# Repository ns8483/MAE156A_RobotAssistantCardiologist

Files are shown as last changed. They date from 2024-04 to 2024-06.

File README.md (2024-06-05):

# MAE156A_RobotAssistantCardiologist
<h2> Contributions:

<h6> Anika Bhattacharya: Knob Engagement and Housing Design and Fabrication<br>
Cristian Nunez-Alcazar: Manuafacturing Lead, Multiplane Angle Mechanism Design and Fabrication<br>
Noah Jones: Custom Stepper and Linear Actuator Libraries, Data Analysis, Tip Control Mechanism Design and Fabrication, Arm Design<br>
Nithya Srinivasan: Software Lead, Knob Engagement Design, Arm Fabrication, Controller Logic and Integration

<h2>Project Background:

<h6>Transesophageal Echocardiography (TEE): ultrasound imaging technique for the heart. It is used to analyze heart defects and guides repair of valves. This procedure is conducted from inside the food pipe (esophagus) via a catheter.
<br><br>

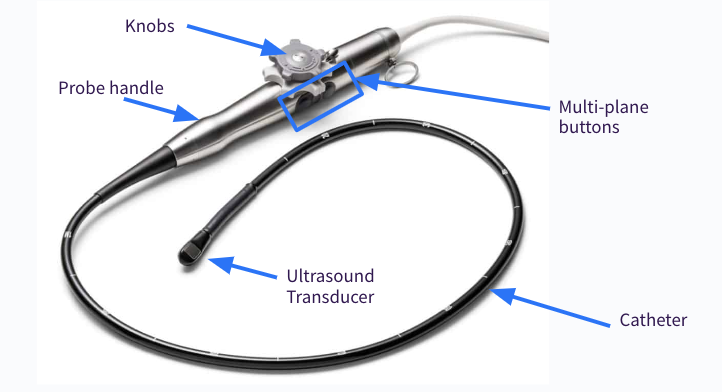
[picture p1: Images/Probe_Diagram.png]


<h2>Problem Definition Overview:

<h6>The current manual procedure is time Consuming (2 hours long), ergonomically challenging, has limited precision, and extensive exposure to harmful x-ray radiation from fluoroscopy.
<br><h4>**Our goal: Remotely operate procedure after initial manual catheter insertion.**</b>

<h6>Diagram of Existing Manual Procedure: <br><br>

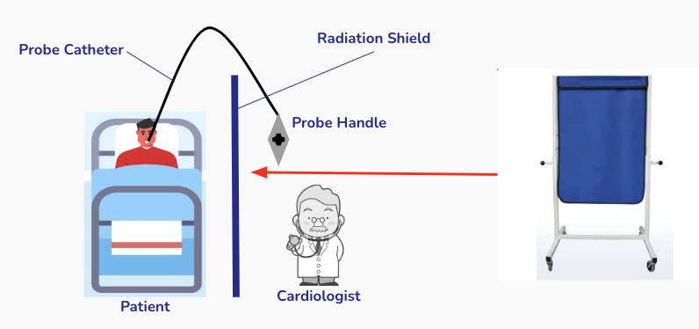
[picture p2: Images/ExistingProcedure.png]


Diagram of Procedure Setup with our Mechanism

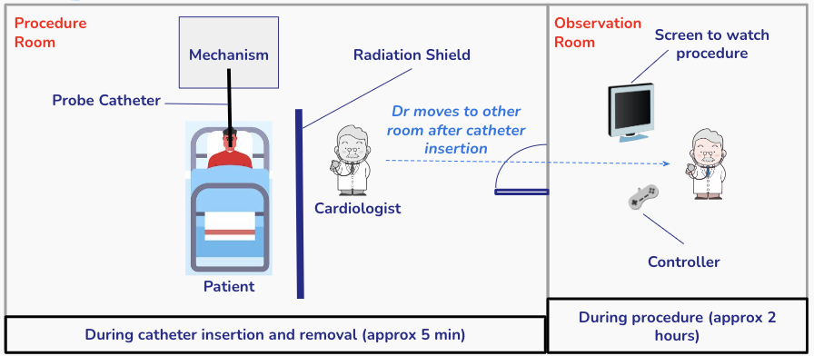
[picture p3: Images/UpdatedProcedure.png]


<h2>Project Video: <br><br>

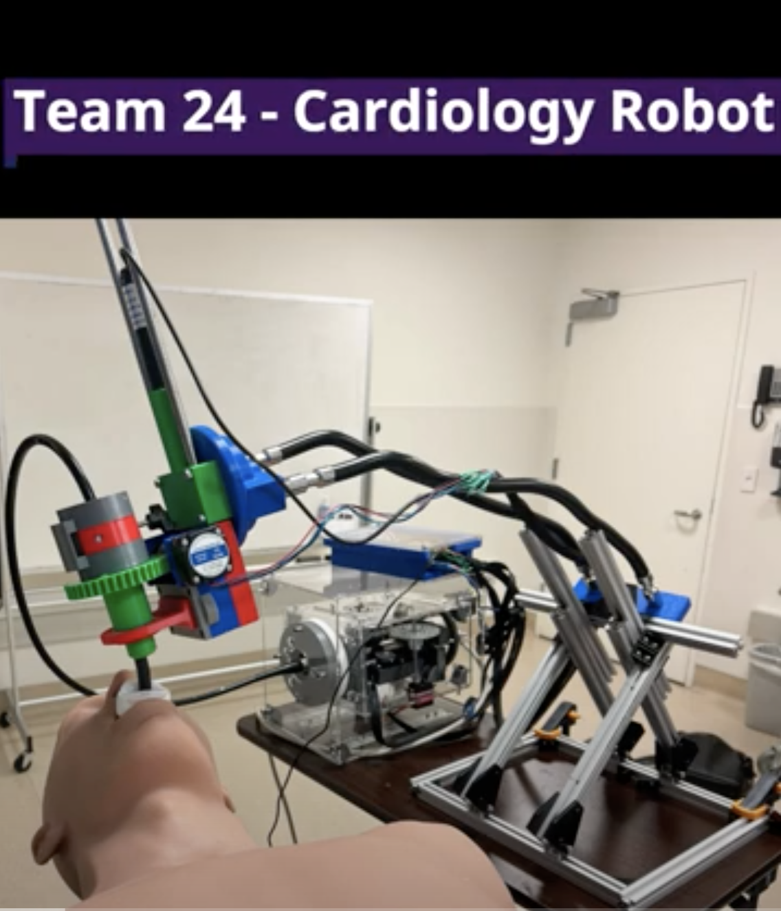
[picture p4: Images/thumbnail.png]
IMAGE ALT TEXT HERE (https://youtu.be/6WJvAoj5yTA?feature=shared)


<h2> Schematic of Overall Design: <br><br>

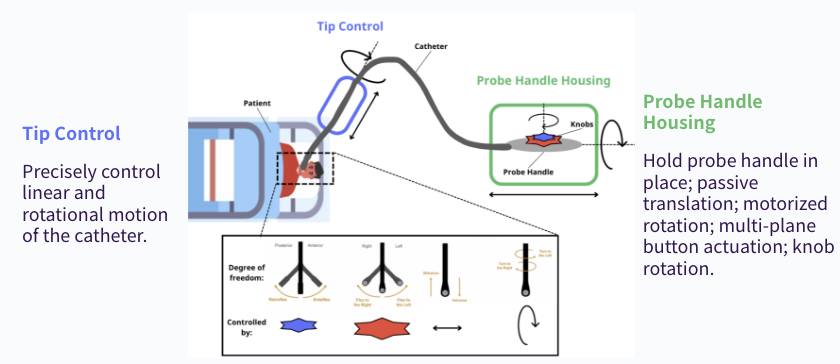
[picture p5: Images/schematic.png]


<h2> CAD Rendering of Design: <br><br>

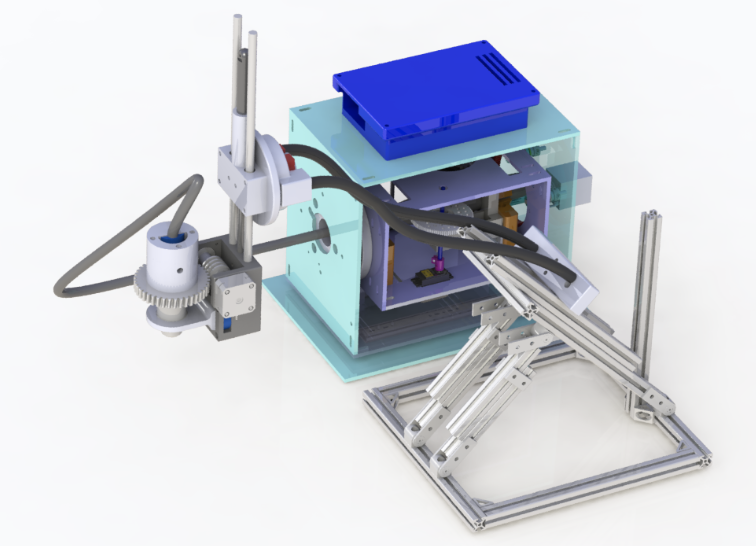
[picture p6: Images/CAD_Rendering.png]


<h2> Final Fabrication: <br><br>

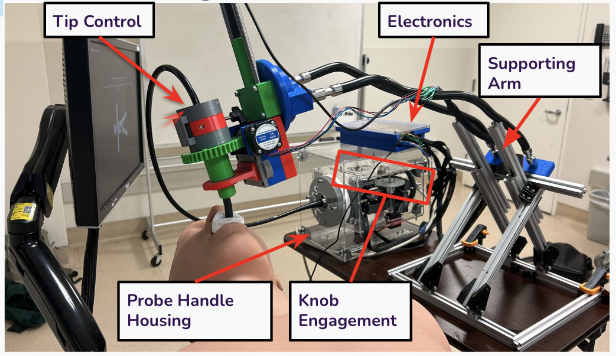
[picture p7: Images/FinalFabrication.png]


<h2> Controller:

<h6> This allows for full control of rotatiton of tip and housing, linear translation, knob engagement, step size adjustment, multi-plane angle control, and position memory as shown in the video.<br>

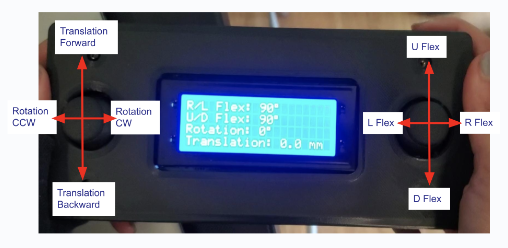
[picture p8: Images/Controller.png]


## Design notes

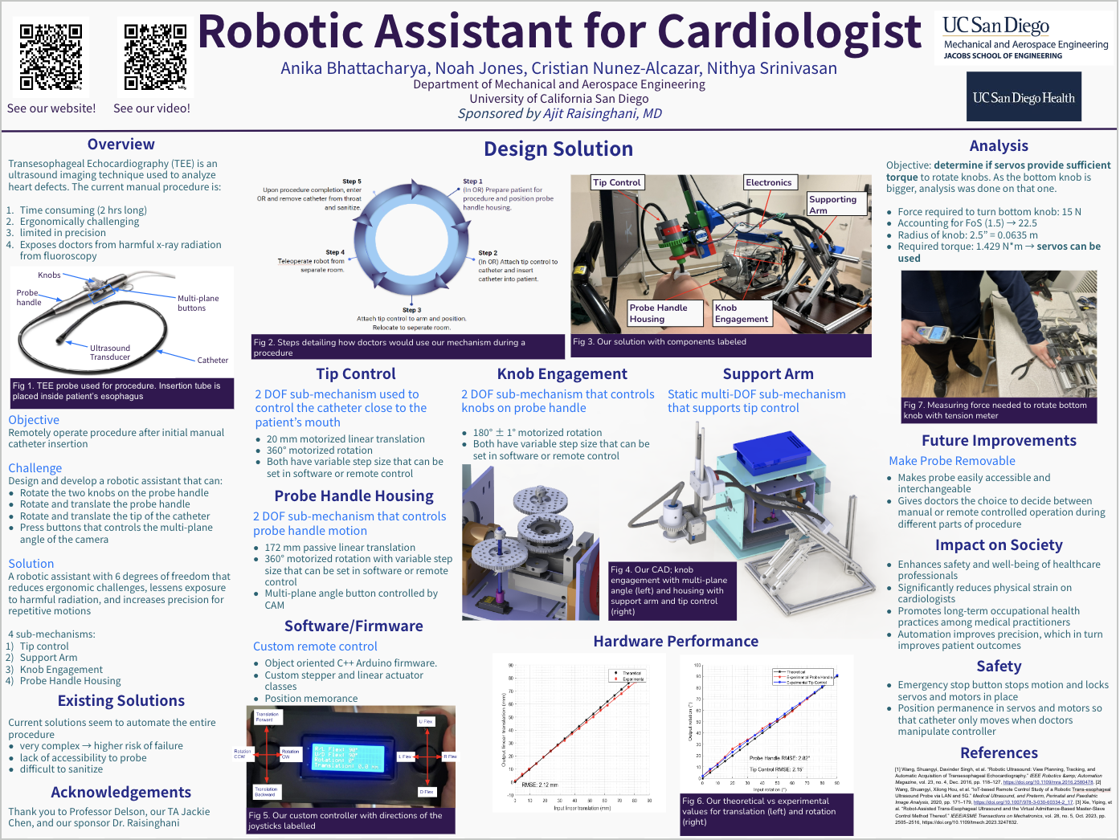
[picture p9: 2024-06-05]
Images/Poster.png

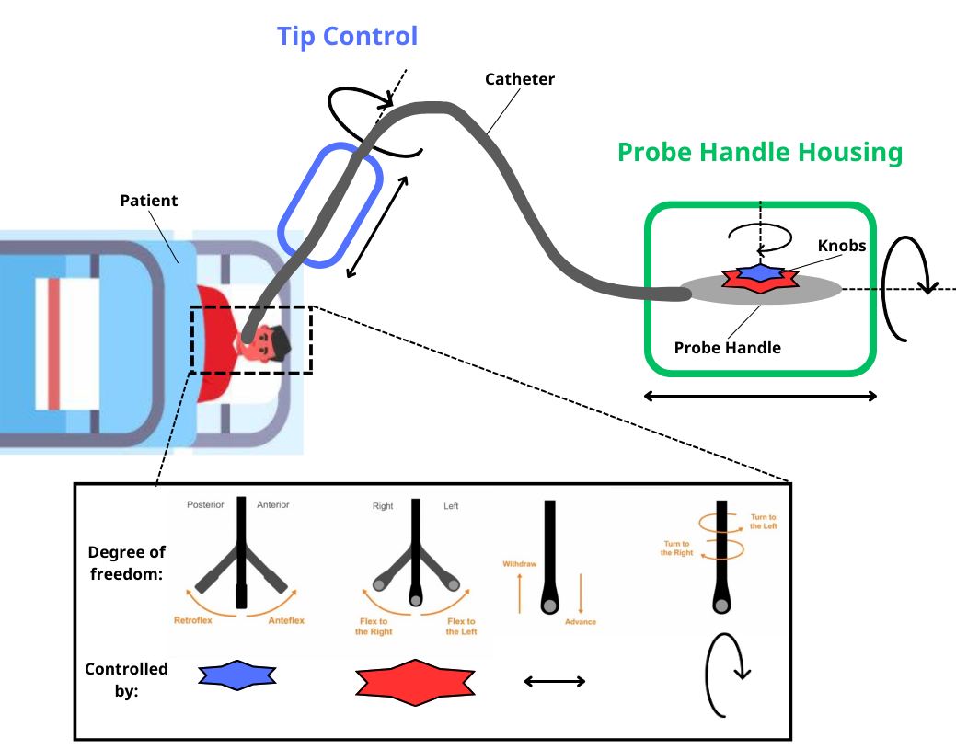
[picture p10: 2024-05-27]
Images/System Diagram Cropped.png

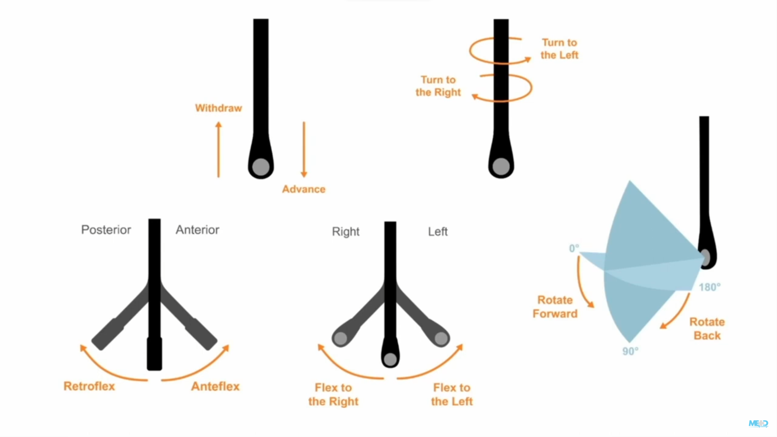
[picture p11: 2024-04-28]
Images/DOfs.png

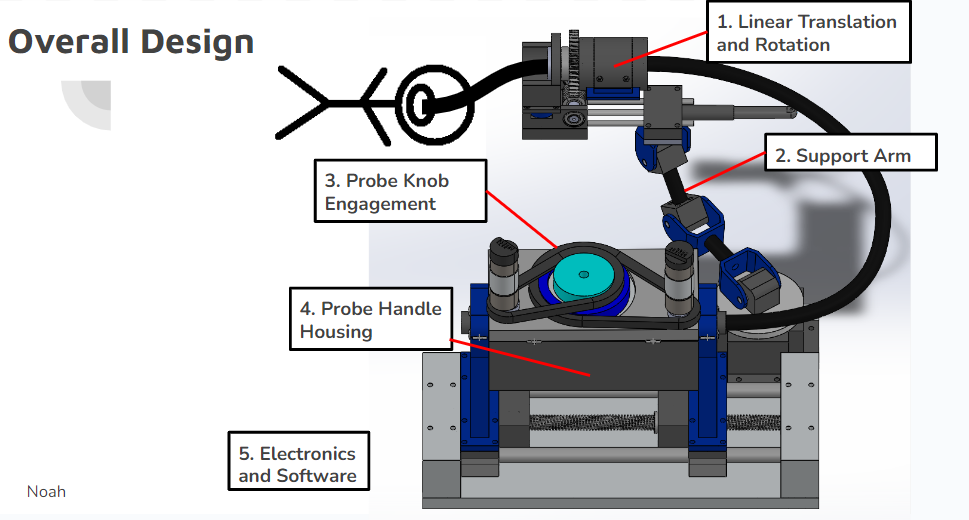
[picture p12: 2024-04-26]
Images/system_diagram.png

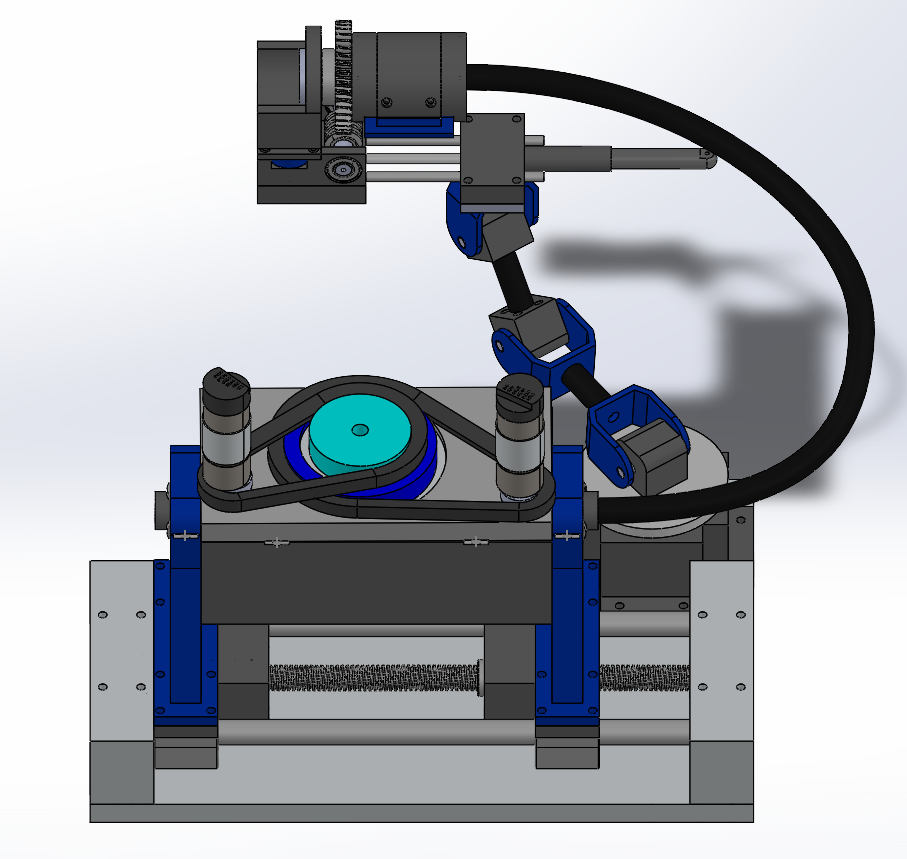
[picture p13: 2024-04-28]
Images/system_model.png

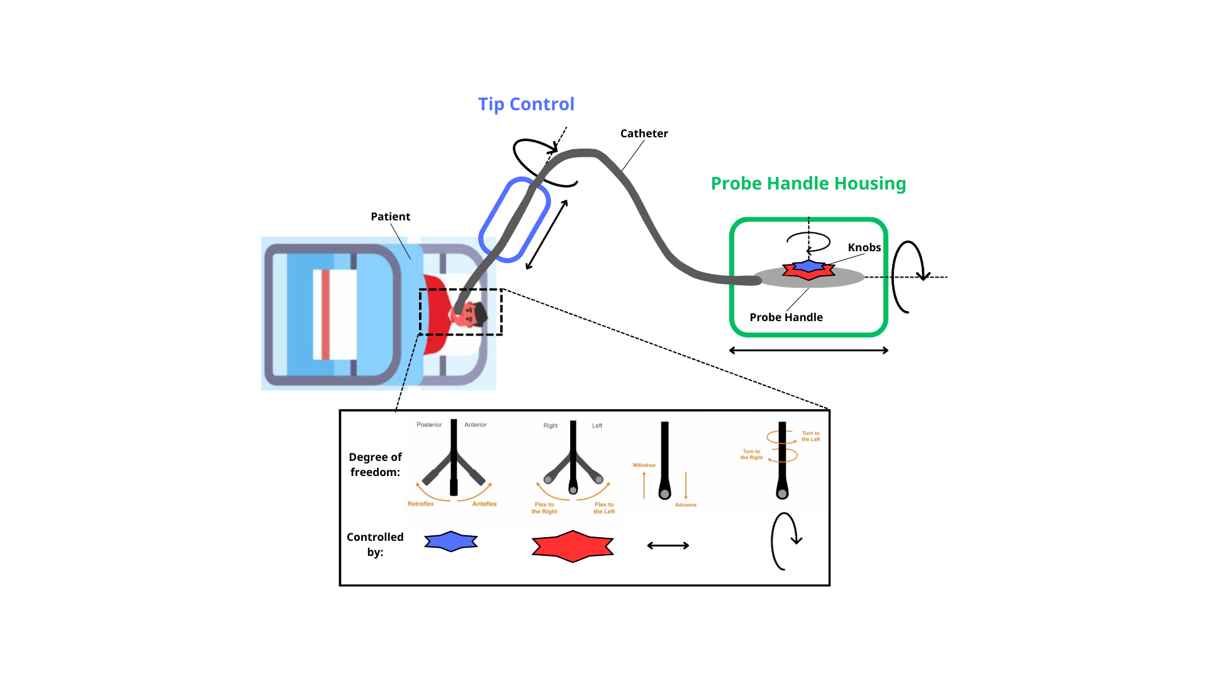
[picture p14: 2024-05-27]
Images/System Diagram.png

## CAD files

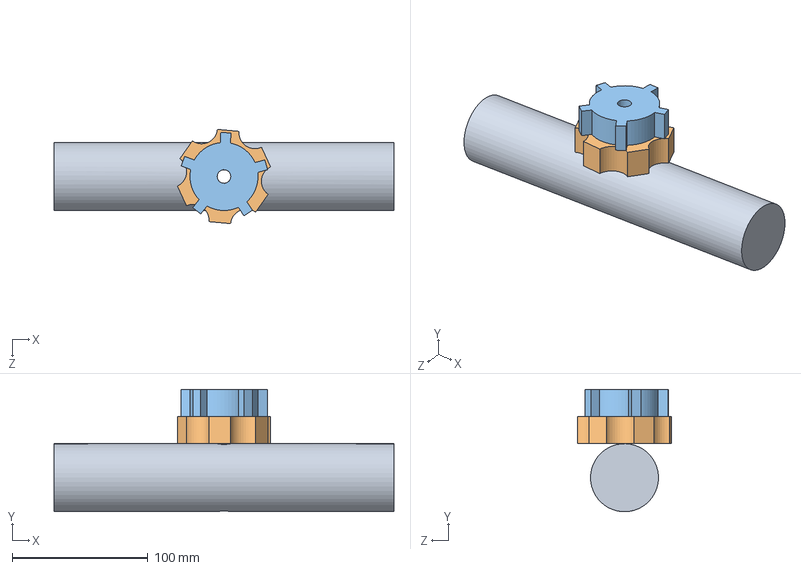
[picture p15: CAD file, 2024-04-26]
CAD/Probe and Housing/probe_mechanism.SLDASM
250.0 x 90.0 x 69.3 mm
probe
big_knob
small_knob

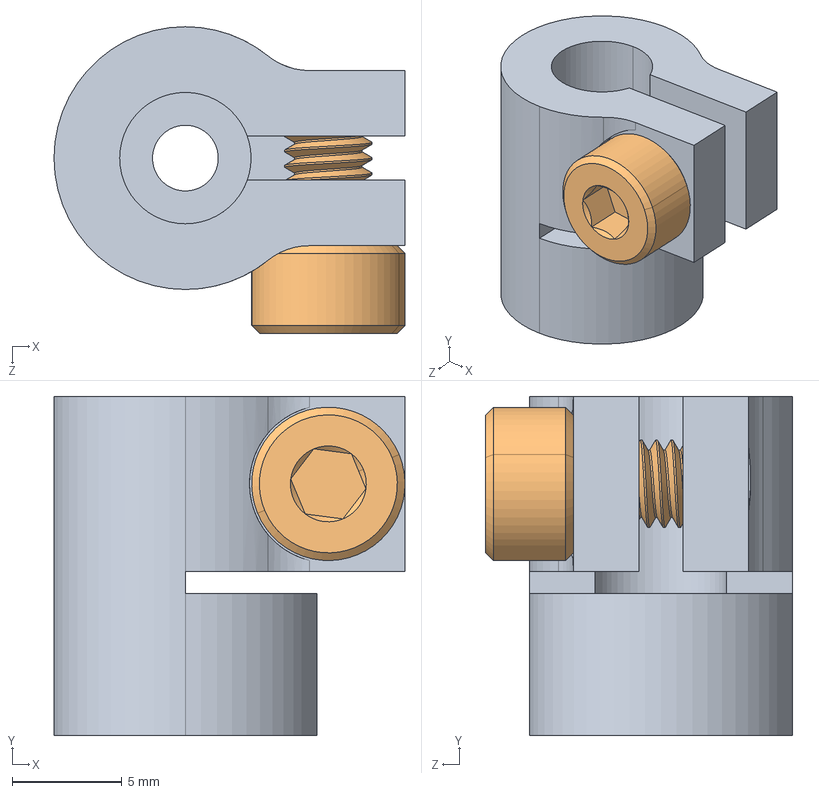
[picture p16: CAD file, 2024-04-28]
CAD/knob engagement, motorized rotation, passive translation/4001-0025-0006 assembly.STEP
16.0 x 15.5 x 14.0 mm
2800-0004-0008_90128A207

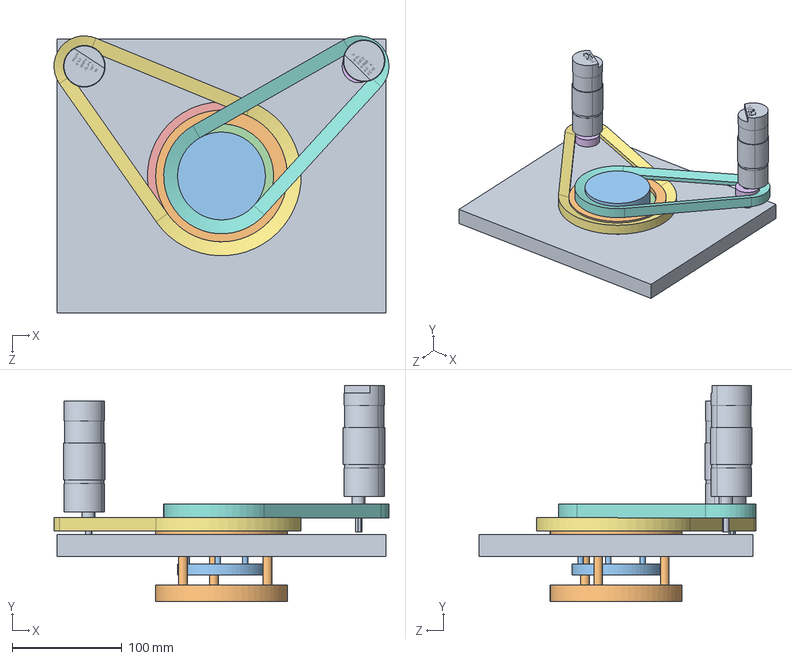
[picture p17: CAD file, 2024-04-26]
CAD/Probe and Housing/top.SLDASM
305.3 x 196.9 x 252.7 mm
lid
big_knob_cap
small_knob_cap
NeedleBearing_PartNumberNTB7095
NeedleBearing_PartNumberNTB100135
dummy pulley x 2
Belt1-8^top
Belt2-9^top
am-2964a Neverest Classic 40 x 2

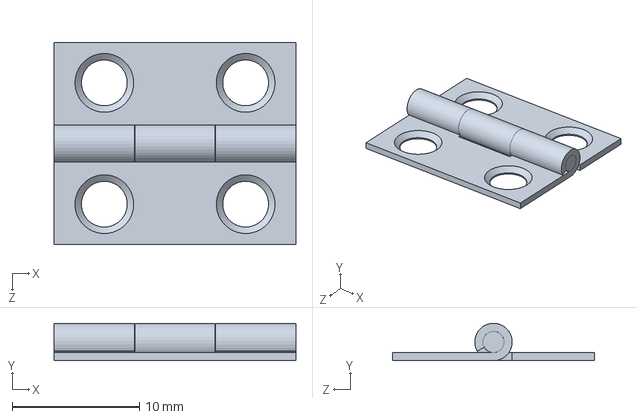
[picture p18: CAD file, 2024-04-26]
CAD/Base/1603A2_Surface-Mount Hinge with Holes.SLDPRT
19.1 x 2.95 x 15.9 mm

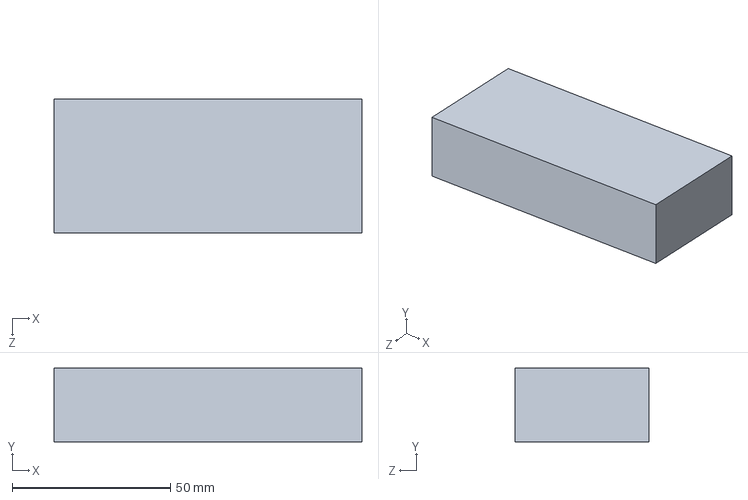
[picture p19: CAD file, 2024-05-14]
CAD/Electronics/Display.SLDPRT
97.3 x 23.2 x 42.4 mm

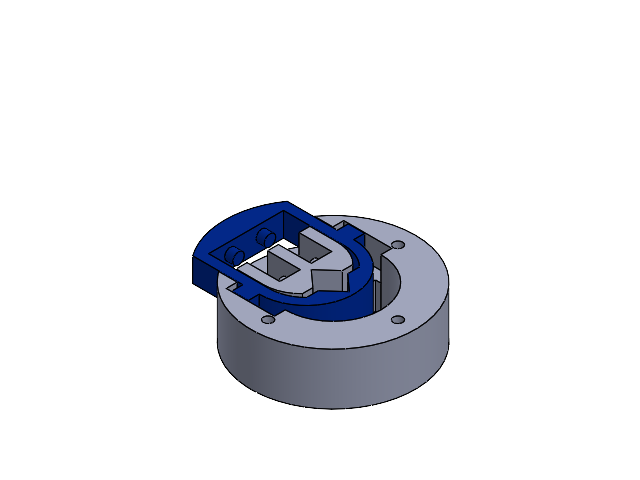
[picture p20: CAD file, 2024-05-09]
CAD/Attachement/Lock Mechanism.SLDASM
Lock Base x 2
Lock Pin
Lock Lid
Lock Internal Block

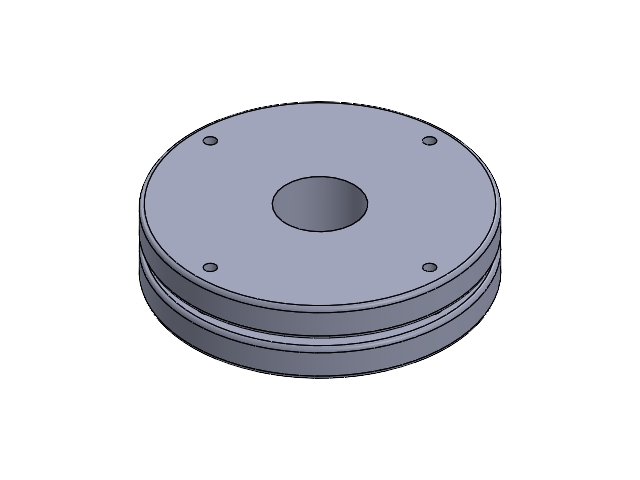
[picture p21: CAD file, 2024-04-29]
CAD/knob engagement, motorized rotation, passive translation/Bearing Mount Assembly.SLDASM
Inner Bearing Mount
5972K295_Ball Bearing 40mm ID
Outer Bearing Mount

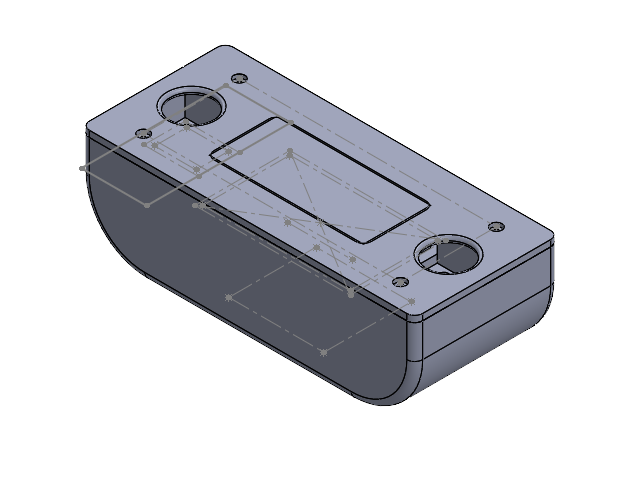
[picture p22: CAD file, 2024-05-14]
CAD/Electronics/Controller Assembly.SLDASM
Controller Back
Controller Front
Display
Controller Lid

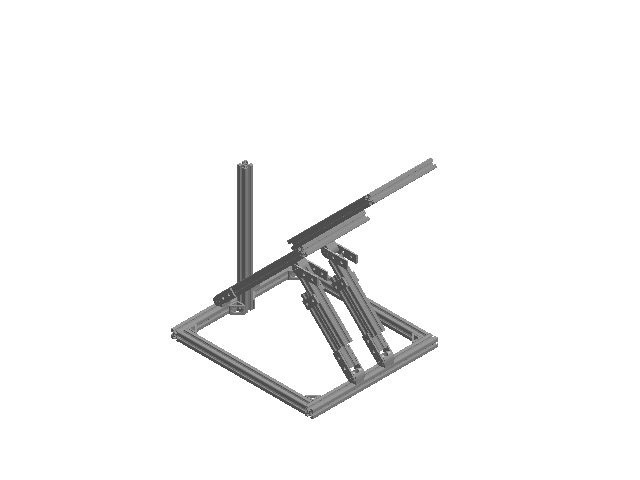
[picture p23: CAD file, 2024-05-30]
CAD/Arm V2/Arm V2.SLDASM
5537T044_T-Slotted Framing x 9
5537T219_T-Slotted Framing x 6
T-Slotted Framing (150mm L) x 6
5537T498_T-Slotted Framing x 8
5537T944_T-Slotted Framing x 4

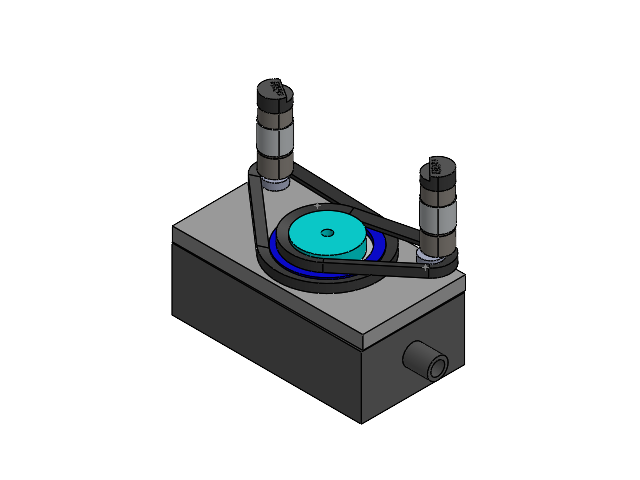
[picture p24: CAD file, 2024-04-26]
CAD/Probe and Housing/Probe and Housing Assembly.SLDASM
New Probe Box
New Probe
lid
big_knob_cap
small_knob_cap
NeedleBearing_PartNumberNTB7095
NeedleBearing_PartNumberNTB100135
dummy pulley x 2
Belt1-8^top
Belt2-9^top
am-2964a Neverest Classic 40 x 2
Dial Large
Dial Small
Hinge 2 x 2
Hinge 1 x 2

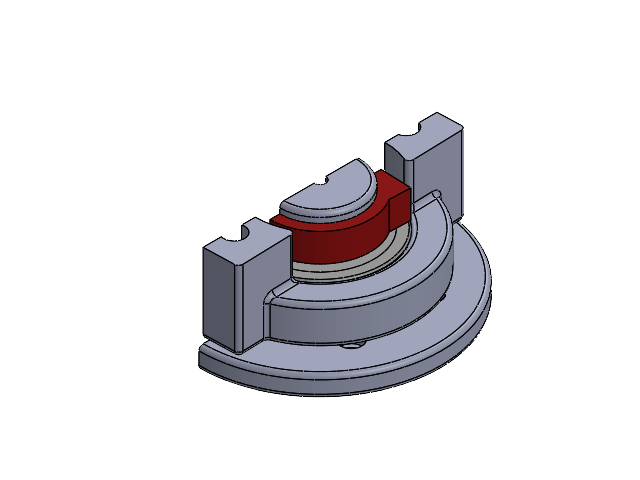
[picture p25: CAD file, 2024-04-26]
CAD/Attachement/Rotator Assembly.SLDASM
Rotator Pin
5972K608_Ball Bearing 30mm ID
Rotator Holder
Rotator Cap
Clamp

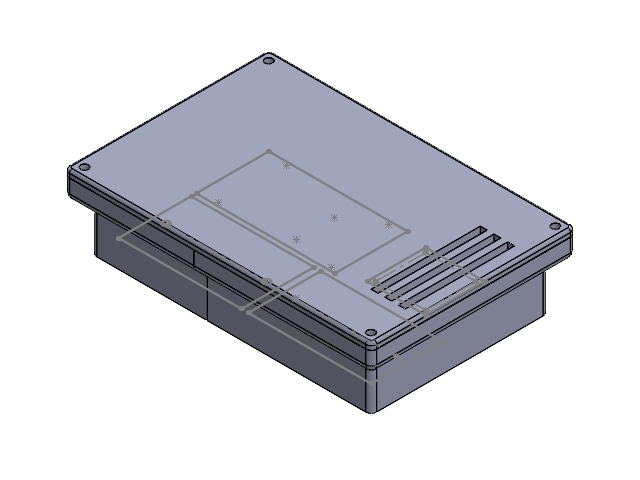
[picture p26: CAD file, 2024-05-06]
CAD/Electronics/Cable Box Assembly.SLDASM
Cable Box (male)
Cable Box (female)
Cable Box Lid

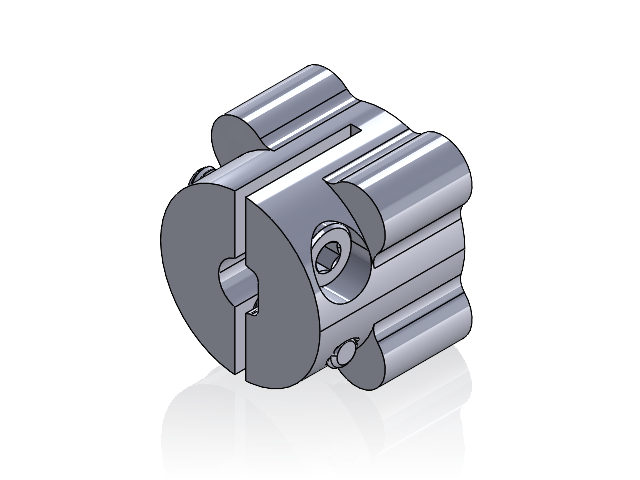
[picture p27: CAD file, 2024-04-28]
CAD/knob engagement, motorized rotation, passive translation/1310-0016-1006 Assembly.SLDASM
1310-0016-1006.STEP
2800-0004-0014_90128A207.STEP x 2

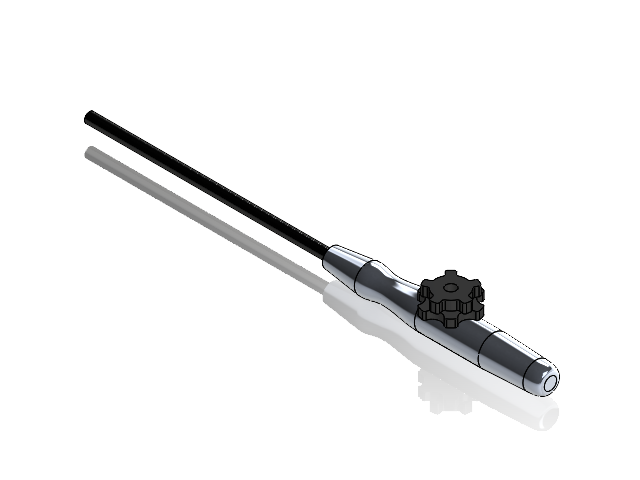
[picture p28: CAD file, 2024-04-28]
CAD/knob engagement, motorized rotation, passive translation/FullProbe.SLDASM
New Probe
Dial Large
Dial Small

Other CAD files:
CAD/Attachement/Micro Linear Actuator 100mm.SLDASM
CAD/Attachement/Square Lock Assembly.SLDASM
CAD/knob engagement, motorized rotation, passive translation/4002-0005-0006 assembly.SLDASM
CAD/Entire Assembly/PJ1045WH Nylon Handle.SLDPRT
CAD/Arm V2/5537T044_T-Slotted Framing.SLDPRT
CAD/Arm V2/5537T219_T-Slotted Framing.SLDPRT
CAD/Arm V2/5537T231_T-Slotted Framing.SLDPRT
CAD/Arm V2/5537T498_T-Slotted Framing.SLDPRT
CAD/Arm V2/5537T944_T-Slotted Framing.SLDPRT
CAD/Arm V2/T-Slotted Framing (150mm L).SLDPRT
CAD/Arm/1.25 D Pipe Mount.SLDPRT
CAD/Arm/3136N723_T-Slotted Framing.SLDPRT
CAD/Arm/5537T915_T-Slotted Framing.SLDPRT
CAD/Arm/Arm Assembly.SLDASM
CAD/Arm/Arm Base Mount.SLDPRT
CAD/Arm/Arm Base Plate.SLDPRT
CAD/Arm/Arm Bracket.SLDPRT
CAD/Arm/Arm Disk.SLDPRT
CAD/Arm/Arm Motor.SLDPRT
CAD/Arm/Arm Mount.SLDPRT
CAD/Arm/Arm Tube Holder.SLDPRT
CAD/Arm/Joint.SLDASM
CAD/Arm/M6x12FHCS_91294A236.SLDPRT
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

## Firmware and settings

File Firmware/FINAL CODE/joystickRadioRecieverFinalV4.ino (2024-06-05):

// Libraries
#include <Servo.h>
#include <SPI.h>
#include <nRF24L01.h>
#include <RF24.h>
#include "LinearActuator.h"
#include "Stepper.h"
// Tip Rotation
int EN_TIP_PIN = 10; // Enable
int STEP_TIP_PIN = 9; // Step
int DIR_TIP_PIN = 13; // Direction
int tipGearRatio = 40; //40:1 ratio
// Handle Rotation
int EN_HANDLE_PIN = 4; // Enable
int STEP_HANDLE_PIN = 6; // Step
int DIR_HANDLE_PIN = 5; // Direction
double handleGearRatio = 6.67; //6.67:1 ratio
// Linear Actuator
int ENA_PIN_NUM = 24; // Motor contoller voltage control (PWM) (change)
int IN1_PIN_NUM = 26; // Motor direction (change)
int IN2_PIN_NUM = 28; // Motor direction (change)
int ENCODERA_PIN_NUM = 3; // Hall Sensor digital signal 
int ENCODERB_PIN_NUM = 2; // 90 deg phase difference
// Knob Rotation
int SERVO_TOP_PIN = 12; // servo for top knob (change)
int SERVO_BOT_PIN = 11; // servo for bottom knob (change)
int servoTopPos = 90; // default position
int prevServoTopPos = servoTopPos; // keeps track of previous servo position
int servoBotPos = 90; // default position
int prevServoBotPos = servoBotPos; // keeps track of previous servo position
// Multiplane Angle Control
int MULTIPLANE_PIN = 44;
int critAnglePos = 30; //CHANGE THESE VALUES OR IT WON'T WORK MIGHT BREAK**************************************
int critAngleNeg = 90;
int neutralAngle = 60;
int multiPlaneMark = 0; //0 means that currently is at neutral, 1 means that currently at CCW mark, -1 means that at CW mark
// NRF Transceiver
int NRF_CSN_PIN = 8;
int NRF_CE_PIN = 7;
int NRF_SCK_PIN = 52;
int NRF_MOSI_PIN = 51;
int NRF_MISO_PIN = 50;
const byte addresses[][6] = {"00001", "00002"};
// Global Vars
float linearStepSize = 1.00; // default linear step size [mm]
float rotationStepSize = 1.00; // default rotation step size [deg]
float servoStepSize = 1.00; // default knob rotation step size [deg]
int microSteps = 8; // default number of stepper microsteps
float joyCritical = 80.0; // Joystick critical actuation value after mapping
float joyPosArray[6] = {}; // [0]: x-right joystick [1]: y-right joystick [2]: x-left joystick [3]: y-left joystick
float posMetrics[4] = {}; // [0]: top servo, [1]: bottom servo, [2]: stepper motor, [3]: linear actuator
//Global objects
Servo servoTop; // top servo object creation
Servo servoBot; // bottom servo object creation
Servo multiplaneServo; //multiplane angle control servo
RF24 radio(NRF_CE_PIN,NRF_CSN_PIN); // radio object creation

//keeps track of what was changed so that can keep track for backtracking.
float prevPos[4] = {90,90,0,0};
float savedPos[4] = {90,90,0,0};

void setup() {
  Serial.begin(115200);
  Serial.println("Calibrating...\n");
  // servo setup
  for(int i=0;i<=servoTopPos;i++){
    servoTop.write(servoTopPos); // send servos to home right away so that will do when attached faster
    servoBot.write(servoBotPos);
    delay(20);
  }
  multiplaneServo.write(neutralAngle);
  servoTop.attach(SERVO_TOP_PIN); // attach feedback pins to servo objects
  servoBot.attach(SERVO_BOT_PIN);
  multiplaneServo.attach(MULTIPLANE_PIN);
  // radio setup
  radio.begin();
  radio.openReadingPipe(1, addresses[1]); // 00002
  radio.openWritingPipe(addresses[0]);
  radio.setPALevel(RF24_PA_MAX);
}

void loop(){
  // initialize class objects
  Stepper stepperTip(EN_TIP_PIN, STEP_TIP_PIN, DIR_TIP_PIN, microSteps, tipGearRatio);
  Stepper stepperHandle (EN_HANDLE_PIN, STEP_HANDLE_PIN, DIR_HANDLE_PIN, microSteps, handleGearRatio);
  Stepper stepperArray[] = {stepperTip, stepperHandle};
  LinearActuator linearActuator(ENA_PIN_NUM, IN1_PIN_NUM, IN2_PIN_NUM, ENCODERA_PIN_NUM, ENCODERB_PIN_NUM);
  Serial.println("Calibrating Complete!");
  while(true) {
    radio.startListening();
    delay(5);
    if (radio.available()) {
      //Serial.println("connected");2
      radio.read(&joyPosArray, sizeof(joyPosArray));
      delay(5);
      //move top servo CW
      if (joyPosArray[0] <= -1*joyCritical){
        if (servoTopPos != 0){
          servoTopPos = servoTopPos - servoStepSize;
          servoTop.write(servoTopPos);
          delay(200); //wait for servo to reach this position
          radio.flush_rx();
          prevPos[0] = servoTopPos;
        }
        //move top servo CCW
      }else if (joyPosArray[0] >= joyCritical){
        if (servoTopPos != 180){
          servoTopPos = servoTopPos + servoStepSize;
          servoTop.write(servoTopPos);
          delay(200); //wait for servo to reach this position
          radio.flush_rx();
          prevPos[0] = servoTopPos;
        }
        //move bottom servo CW
      }else if (joyPosArray[1] <= -1*joyCritical){
        if (servoBotPos != 0){
          servoBotPos = servoBotPos - servoStepSize;
          servoBot.write(servoBotPos);
          delay(200); //wait for servo to reach this position
          radio.flush_rx();
          prevPos[1] = servoBotPos;
        }
        //move botttom servo CCW
      }else if (joyPosArray[1] >= joyCritical){
        if (servoBotPos != 180){
          servoBotPos = servoBotPos + servoStepSize;
          servoBot.write(servoBotPos);
          delay(200); //wait for servo to reach this position
          radio.flush_rx();
          prevPos[1] = servoBotPos;
        }
        //stepper CCW rotation
      }else if (joyPosArray[2] >= joyCritical){ // if left joystick points right and stepper is not already moving
        Stepper::incrementalPosMulti(rotationStepSize,0,stepperArray); // synchronous stepper movement direction 1 (CW)
        radio.flush_rx();
        prevPos[2] = stepperArray[0].currentAngle;
        //stepper CW rotation
      }else if (joyPosArray[2] <= -1*joyCritical){ // if left joystick points left and stepper is not already moving
        Stepper::incrementalPosMulti(rotationStepSize,1,stepperArray); // synchronous stepper movement direction 0 (CCW)
        radio.flush_rx();
        prevPos[2] = stepperArray[0].currentAngle;
        //linear actuator extension
      }else if (joyPosArray[3] >= joyCritical){ // if left joystick points up
        linearActuator.incrementalPos(linearStepSize, 1); // linear actuator extension
        radio.flush_rx();
        prevPos[3] = linearActuator.position;
        //linear actuator retraction
      }else if (joyPosArray[3] <= -1*joyCritical){ // if left joystick points down
        linearActuator.incrementalPos(linearStepSize, 0); // linear actuator retraction
        radio.flush_rx();
        prevPos[3] = linearActuator.position;
      }
      //look in transmitter code for explanation of this element
        //1 and 2 denote new step size change of servos, 3 is for stepper, 4 is for linear actuator
      else if (joyPosArray[4] == 1){
        servoStepSize = servoStepSize + 1;
      } else if (joyPosArray[4] == -1) {
        servoStepSize = servoStepSize - 1;
      } else if (joyPosArray[4] == 2) {
        rotationStepSize = rotationStepSize + 1;
      } else if (joyPosArray[4] == -2) {
        rotationStepSize = rotationStepSize - 1;
      } else if (joyPosArray[4] == 3) {
        linearStepSize = 5*linearStepSize;
      } else if (joyPosArray[4] == -3) {
        linearStepSize = 0.5*linearStepSize;
      } //controls multiplane buttons
          //servo rotates between pressing each button and neutral positions
      else if (joyPosArray[5] == 1) {
        if (multiPlaneMark < 1) {
          if (multiPlaneMark ==0) {
            multiplaneServo.write(critAnglePos);
            multiPlaneMark = 1;
          } else if ( multiPlaneMark== -1) {
            multiplaneServo.write(neutralAngle);
            multiPlaneMark = 0;
          }
          delay(200);
          radio.flush_rx();
        }
        Serial.println(multiPlaneMark);
        Serial.println(multiplaneServo.read());
      } else if(joyPosArray[5] == -1) {
        if (multiPlaneMark > -1) {
          if (multiPlaneMark ==0) {
            multiplaneServo.write(critAngleNeg);
            multiPlaneMark = -1;
          } else if (multiPlaneMark == 1) {
            multiplaneServo.write(neutralAngle);
            multiPlaneMark = 0;
          }
          delay(200);
          radio.flush_rx();
        }
        Serial.println(multiPlaneMark);
        Serial.println(multiplaneServo.read());
      }
      //look in transmitter code for explanation of this element
        //can save and restore positions
      else if (joyPosArray[5] == 2) {
        //saving position
        Serial.println("**************************");
        Serial.println(prevPos[0]);
        Serial.println(prevPos[1]);
        Serial.println(prevPos[2]);
        Serial.println(prevPos[3]);
        Serial.println("**************************");
        for (int i = 0; i < 4; i++) {
          savedPos[i] = prevPos[i];
        }
      } else if (joyPosArray[5] == 3) {
        //restoring position
        Serial.println("**************************");
        Serial.println(savedPos[0]);
        Serial.println(savedPos[1]);
        Serial.println(savedPos[2]);
        Serial.println(savedPos[3]);
        Serial.println("**************************");
        servoTop.write(savedPos[0]);
        servoTopPos = savedPos[0];
        radio.flush_rx();
        servoBot.write(savedPos[1]);
        servoBotPos = savedPos[1];
        radio.flush_rx();
        float stepperDiff = stepperArray[0].currentAngle - savedPos[2];
        if (stepperDiff < 0) {
          Stepper::incrementalPosMulti(abs(stepperDiff),1,stepperArray); // synchronous stepper movement direction 0 (CCW)
          radio.flush_rx();
        } else {
          Stepper::incrementalPosMulti(abs(stepperDiff),0,stepperArray); // synchronous stepper movement direction 0 (CCW)
          radio.flush_rx();
        }
        float linDiff = linearActuator.position - savedPos[3];
        if (linDiff < 0) {
          linearActuator.incrementalPos(abs(linDiff), 1);
          radio.flush_rx();
        } else {
          linearActuator.incrementalPos(abs(linDiff), 0);
          radio.flush_rx();
        }
      }
    }
    radio.flush_rx();
    radio.stopListening();
    delay(5);
    //writing to controller to update LCD display
    posMetrics[0] = servoTopPos;
    posMetrics[1] = servoBotPos;
    posMetrics[2] = stepperArray[0].currentAngle;
    posMetrics[3] = linearActuator.position;
    radio.write(&posMetrics, sizeof(posMetrics));
  }
}

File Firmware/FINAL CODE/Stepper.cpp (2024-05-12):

/*
  Stepper.cpp - Library for controlling Stepper Motors.
  Provides simultaneously, non-blocking stepper motor control,
  that adjusts for gear ratio discrepancies to maintain synchronized speeds.

  Created by Noah L. Jones, May 10, 2024.
  Released into the public domain.
*/

#include "Stepper.h"
#include "Arduino.h"

// Setup Constructor 
Stepper::Stepper(int EN_PIN_NUM, int STEP_PIN_NUM, int DIR_PIN_NUM, int microStepNum, double gearRatioNum) {
  enPin = EN_PIN_NUM;
  stepPin = STEP_PIN_NUM;
  dirPin = DIR_PIN_NUM;
  microSteps = microStepNum;
  gearRatio = gearRatioNum;
  stepsPerRevolution = 200*microSteps;  // Change this according to your motor's specification
  pinMode(enPin, OUTPUT);
  pinMode(stepPin, OUTPUT);
  pinMode(dirPin, OUTPUT);
  digitalWrite(enPin,LOW); // Enable TMC2209
}

void Stepper::singleStep(){
  digitalWrite(stepPin, HIGH); // Cycle otor once
  delayMicroseconds(50);
  digitalWrite(stepPin, LOW);
  delayMicroseconds(50);
  if (stepperDir == 0){
    currentAngle = currentAngle - 360.00/(static_cast<double>(stepsPerRevolution)*static_cast<double>(gearRatio)); // update current angle (negative for CW)
  } else{
    currentAngle = currentAngle + 360.00/(static_cast<double>(stepsPerRevolution)*static_cast<double>(gearRatio)); // update current angle (positive for CCW)
  }
  Serial.println("\nCurrent Angle: " + String(currentAngle) + " deg");
}

void Stepper::changeDirection(int chosenDirection) {
  if (chosenDirection == 0) { // CW 
    digitalWrite(dirPin, LOW);
    stepperDir = 0;
  } else if (chosenDirection == 1) { // CCW 
    digitalWrite(dirPin, HIGH);
    stepperDir = 1;
  }
}

void Stepper::incrementalPos(float deltaTheta, int direction){
  changeDirection(direction); // update direction
  while(!finishedTargetSteps(deltaTheta)) {  // do single steps until finished rotating by deltaTheta  
    singleStep();
  }
}

static void Stepper::incrementalPosMulti(float deltaTheta, int direction, Stepper instances[]){
  bool complete[sizeof(instances)]; // create a complete condition for each instance
  float percentComplete[sizeof(instances)]; // create an array of percentages for how close motor is to target  
  float criticalMotorPercentage = 0; // smallest motor percentage
  for (int i = 0; i < sizeof(instances); i++) {
    instances[i].changeDirection(direction); // change direction
    complete[i] = false; // set initial complete conditions to false
    percentComplete[i] = 0.000; // set initial percentComplete values to 0
  }
  while(!allConditionsMet(complete)){ // loop until all rotations are complete
    for (int i = 0; i < sizeof(instances); i++) { // loop through all instances
      if(percentComplete[i] <= criticalMotorPercentage && !complete[i]){ // if motor is furthest from completing and has not yet complete
        if(!instances[i].finishedTargetSteps(deltaTheta)){ // if specific instance has not returned true for finishedRotating()
          instances[i].singleStep(); // make a single step
          percentComplete[i] = instances[i].steps/instances[i].targetSteps;
          criticalMotorPercentage = percentComplete[i]; // update criticalMotorPercentage 
        } else {
          complete[i] = true; // rotation for this instance finished
        }
      } else if(percentComplete[i] >= 1){ // if rotation has gone past completion
          complete[i] = true; // rotation for this instance finished
      }
    }
  }
  //Serial.println("Multi Rotation Finished");
}

bool Stepper::finishedTargetSteps(float deltaTheta) { 
  if(finishedMoving) { 
    steps = 0;
    targetSteps = (deltaTheta/360)*stepsPerRevolution*gearRatio;
    finishedMoving = false;
  }
  Serial.println("\n steps: " + String(steps) + "\ntargetSteps: " + String(targetSteps) + "\ngear ratio" + String(gearRatio));
  if (steps < targetSteps){
    steps ++; //add a step
  }
  if (steps >= targetSteps){
    finishedMoving = true;
    return 1; // finsihed rev
  } else {
    return 0; // not finsihed rev
  }
}

static bool Stepper::allConditionsMet(bool conditions[]) { // method to check if all members in array are true
  for(int i = 0; i < sizeof(conditions); i++) {
    if(!conditions[i]) {
      return false;
    }
  }
  return true;
}

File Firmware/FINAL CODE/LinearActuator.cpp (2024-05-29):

/*
  LinearActuator.h - Library for controlling Firgelli Micro Pen Actuator with Feedback.

  Created by Noah L. Jones, May 10, 2024.
  Released into the public domain.
*/

#include "LinearActuator.h"
#include "Arduino.h"

LinearActuator* LinearActuator::instancePointer = nullptr;
bool LinearActuator::finishedMoving = true;

static void LinearActuator::interruptHandler() {
  if (instancePointer != nullptr) {
        instancePointer->encoderUpdatePos();
    }
}

void LinearActuator::encoderUpdatePos() { // attachInterrupt() function requires a static function as its argument
  static boolean A_prev = false;
  static boolean B_prev = false;
  boolean A_current = digitalRead(encoderAPin) == HIGH;
  boolean B_current = digitalRead(encoderBPin) == HIGH;

  if (A_prev && !A_current && B_prev && B_current) {
    // CW transition: A goes LOW before B
    rotDir = 1; // extending
    position = position + pulseFraction; // add to current position
  } else if (A_prev && A_current && B_prev && !B_current) {
    // CCW transition: B goes LOW before A
    rotDir = 0; // retracting
    position = position - pulseFraction; // subtract from current position
  }

  A_prev = A_current;
  B_prev = B_current;
  //Serial.println(String(A_prev) + String(B_prev));
  //Serial.println(String("Current Position: ") + String(position) + String(" mm\n"));
}

LinearActuator::LinearActuator(int ENA_PIN_NUM, int IN1_PIN_NUM, int IN2_PIN_NUM, int ENCODERA_PIN_NUM, int ENCODERB_PIN_NUM) {
  enAPin = ENA_PIN_NUM;
  in1Pin = IN1_PIN_NUM;
  in2Pin = IN2_PIN_NUM;
  encoderAPin = ENCODERA_PIN_NUM;
  encoderBPin = ENCODERB_PIN_NUM;
  pinMode(enAPin, OUTPUT);
  pinMode(in1Pin, OUTPUT);
  pinMode(in2Pin, OUTPUT);
  pinMode(encoderAPin, INPUT_PULLUP);
  pinMode(encoderBPin, INPUT_PULLUP);
  instancePointer = this; // Set the instance pointer to this object
  attachInterrupt(digitalPinToInterrupt(encoderAPin), interruptHandler, CHANGE); // Check for changes on feedback pins
  attachInterrupt(digitalPinToInterrupt(encoderBPin), interruptHandler, CHANGE);
  while(!isCalibrated()){} // wait until actuator has finished calibrating
}

void LinearActuator::changeDirection(int chosenDirection) {
  if (chosenDirection == 1) { // if chosen to extend
        digitalWrite(in1Pin, HIGH);
        digitalWrite(in2Pin, LOW);
        analogWrite(enAPin, power);
        rotDir = 1;
  } else if (chosenDirection == 0) { // if chosen to retarct
        digitalWrite(in1Pin, LOW);
        digitalWrite(in2Pin, HIGH);
        analogWrite(enAPin, power);
        rotDir = 0;
  }
}

void LinearActuator::stopActuator() {
  digitalWrite(in1Pin, LOW); // stop
  digitalWrite(in2Pin, LOW);
  analogWrite(enAPin, 0); // disable actuator
}

void LinearActuator::incrementalPos(float deltaX, int direction) {
  if(position-deltaX < 0 && direction == 0){return;} // cancel operation if trying to retract past home
  if(direction == 0){deltaX = -1*deltaX;} // negative deltaX for retraction
  changeDirection(direction); // change direction of actuator to chosen
  while(!finishedTargetSteps(deltaX)) {} // wait for step completion
  stopActuator();
  delay(200); // wait for motor to decelerate 
}

bool LinearActuator::finishedTargetSteps(float deltaX) {
  if((deltaX < 0 && !(decelerationPosError < 0)) || (deltaX > 0 && !(decelerationPosError > 0))){
    decelerationPosError = -1*decelerationPosError; // if posError has wrong sign for movement, update it
    }
  static float oldPosition = position; // set initial position to current position
  static float targetPosition = oldPosition + deltaX - decelerationPosError; // calculate targetPosition 
  // update the statics with new values upon successful prior completion
  if(finishedMoving) {
    oldPosition = position;
    targetPosition = oldPosition + deltaX - decelerationPosError;
    finishedMoving = false;
  }
  //Serial.println("\n3Target: " + String(targetPosition) + "\n Old: " + String(oldPosition) + "\n Current: " + String(position) + "\n Step: " + String(deltaX) + "\n direction: " + String(rotDir) + String("posError: ") + String(decelerationPosError));
  // check to see if target has been met
  if(rotDir == 1) { // if extending
    if(position >= targetPosition){ // if position has reached target position 
      finishedMoving = true; // actuator has reached target and finished
      return 1; // return true
    } else {
      return 0; // actuator still extending return false
    }
  } else if(rotDir == 0) { // if retracting
    if(position <= targetPosition){ // if position has reached target position 
      finishedMoving = true; // actuator has reached target and finished 
      return 1; // return true
    } else {
      return 0; // actuator still retracting return false
    }
  }
}

bool LinearActuator::isCalibrated(){
  changeDirection(0); // retract
  delay(50); // wait for actuator to start moving
  while (!isZerod(position)) { //wait until actuator is zerod
    delay(50);
  }
  changeDirection(1); // add 1 mm offset
  while(!finishedTargetSteps(1.00)) {}; 
  stopActuator(); // stop movement 
  delay(500);
  position = 0; // set home position to zero
  return 1;
}

bool LinearActuator::isZerod(float x) {
  static float old_value = 1; // give x some random placeholder value
  if(x != old_value) {
    // actuator is still detracting
    old_value = x;
    return 0;
  } else {
    // actuator is done detracting
    return 1;
  }
}

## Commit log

2024-04-26 CAD Update Noah
    [0.5in Side Ball Bearing.SLDPRT, 1.25 D Pipe Mount.SLDPRT, 10mm ID.SLDPRT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]
2024-04-28 Anika Knob Engagement
    [1310-0016-1006 Assembly.SLDASM, 2101-0006-0060.SLDPRT, 2101-0006-0060.STEP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]
2024-04-28 Add files via upload
    need to run with rest of library, just committed modified files. servo is controlled with xbox controller using computer, not bluetooth module. just was an experiment lol
2024-04-28 Add files via upload
    experiment where servo was controlled through keyboard
2024-04-28 Add files via upload
    servo bluetooth integration with xbox controller
2024-04-28 Add files via upload
    demo of the knobs rotating with servo motors
2024-04-29 Noah updates
    [5972K295_Ball Bearing 40mm ID.SLDPRT, Bearing Mount Assembly.SLDASM, Cable Box Assembly.SLDASM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]
2024-05-06 Code Noah
    [Cable Box (female).SLDPRT, Cable Box (male).SLDPRT, Cable Box Assembly.SLDASM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]
2024-05-08 Add files via upload
    debugged linear actuator code and combined with bluetooth functionality and servo control- adjusted 1 degree steps for stepper motors
2024-05-09 Add files via upload
    uses serial radio transmission from one arduino (nano) to the other (mega) for control using two joysticks. not yet tested or debugged
2024-05-11 Add files via upload
    fixed variable definition bug and verified that it works with serial monitor
    [joystickRadioTransmitterFinalV2.ino]
2024-05-11 Add files via upload
    adjusted joystick max and min values in all directions after testing and added tolerance in each direction
    [joystickRadioRecieverFinalV2.ino]
2024-05-11 Add files via upload
    cleaned up code and debugged, added libraries (.h andd .cpp files) for linear actuator and stepper so it is easier to modify.
2024-05-12 Add files via upload
    bi directional radio communication and hopefully fixes noise in servos
    [joystickRadioRecieverFinalV3.ino]
2024-05-12 Add files via upload
    added delay for servos, decided this is best way to wait for them to reach position
2024-05-28 Add files via upload
    updated menu and fixed bugs/ simplified code
    [joystickRadioTransmitterFinalV4.ino]
2024-05-30 Add files via upload
    easier to use libraries this way, fixed connection bug and did backtracking
    [LinearActuator.cpp, LinearActuator.h, Stepper.cpp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]
2024-05-30 Add files via upload
    fixed connection bug and did backtracking
    [joystickRadioTransmitterFinalV4.ino]
